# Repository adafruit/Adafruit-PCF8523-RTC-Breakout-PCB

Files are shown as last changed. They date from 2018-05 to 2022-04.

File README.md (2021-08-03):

## Adafruit PCF8523 RTC Breakout PCB

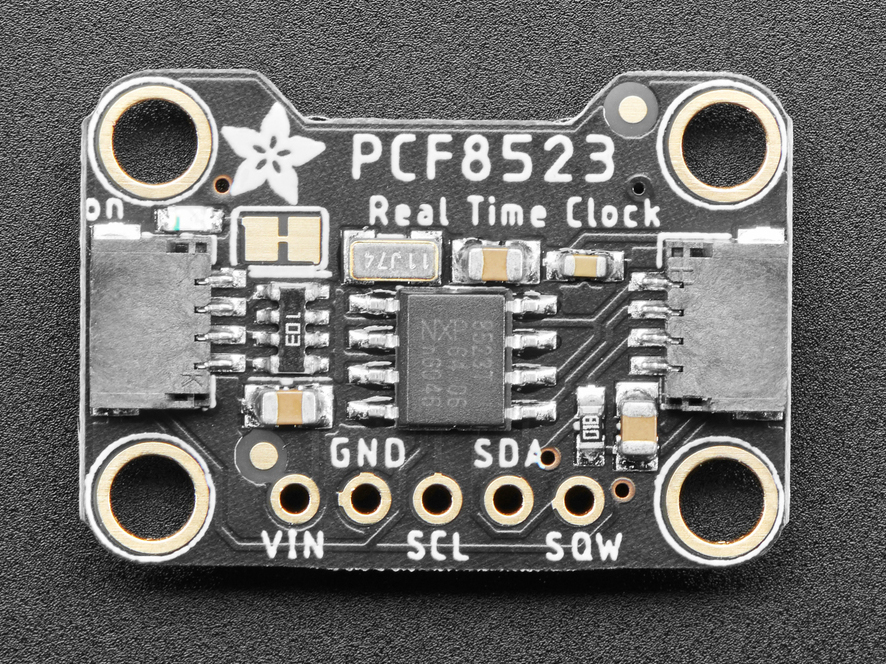
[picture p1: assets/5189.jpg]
<a href="http://www.adafruit.com/products/5189"><br/>
Click here to purchase one from the Adafruit shop</a>

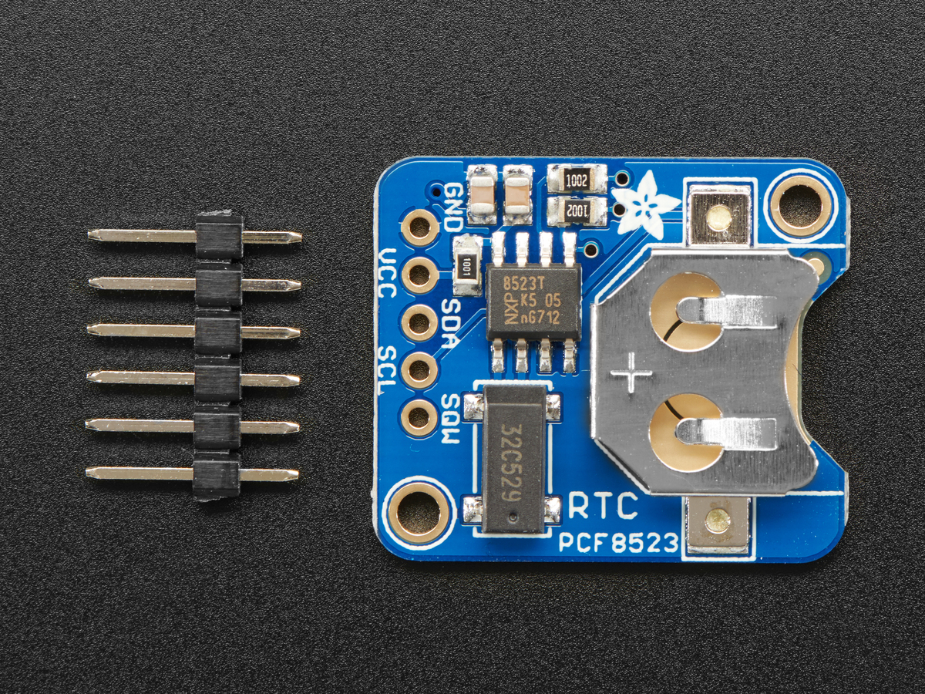
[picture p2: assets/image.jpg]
<a href="http://www.adafruit.com/products/3295"><br/>
Click here to purchase one from the Adafruit shop</a>

PCB files for the Adafruit PCF8523 RTC Breakout. Format is EagleCAD schematic and board layout

For more details, check out the product pages at
* https://www.adafruit.com/products/3295

### Description

This is a great battery-backed real time clock (RTC) that allows your microcontroller project to keep track of time even if it is reprogrammed, or if the power is lost. Perfect for datalogging, clock-building, time stamping, timers and alarms, etc. Equipped with PCF8523 RTC - it can run from 3.3V or 5V power & logic!

Works great with an Arduino using our RTC library, with CircuitPython or with a Raspberry Pi (or similar single board linux computer)

* PCB & header are included
* Plugs into any breadboard, or you can use wires
* Two mounting holes
* Will keep time for 5 years or more

**Note: This product does not come with a CR1220 coin cell battery. We recommend you purchase a coin cell battery to use with this product.**

The PCF8523 is simple and inexpensive but not a high precision device. It may lose or gain up to 2 seconds a day. For a high-precision, temperature compensated alternative, please check out the DS3231 precision RTC. If you need a DS1307 for compatibility reasons, check out our DS1307 RTC breakout

### License

Adafruit invests time and resources providing this open source design, please support Adafruit and open-source hardware by purchasing products from [Adafruit](https://www.adafruit.com)!

Designed by Limor Fried/Ladyada for Adafruit Industries.

Creative Commons Attribution/Share-Alike, all text above must be included in any redistribution. See license.txt for additional details.

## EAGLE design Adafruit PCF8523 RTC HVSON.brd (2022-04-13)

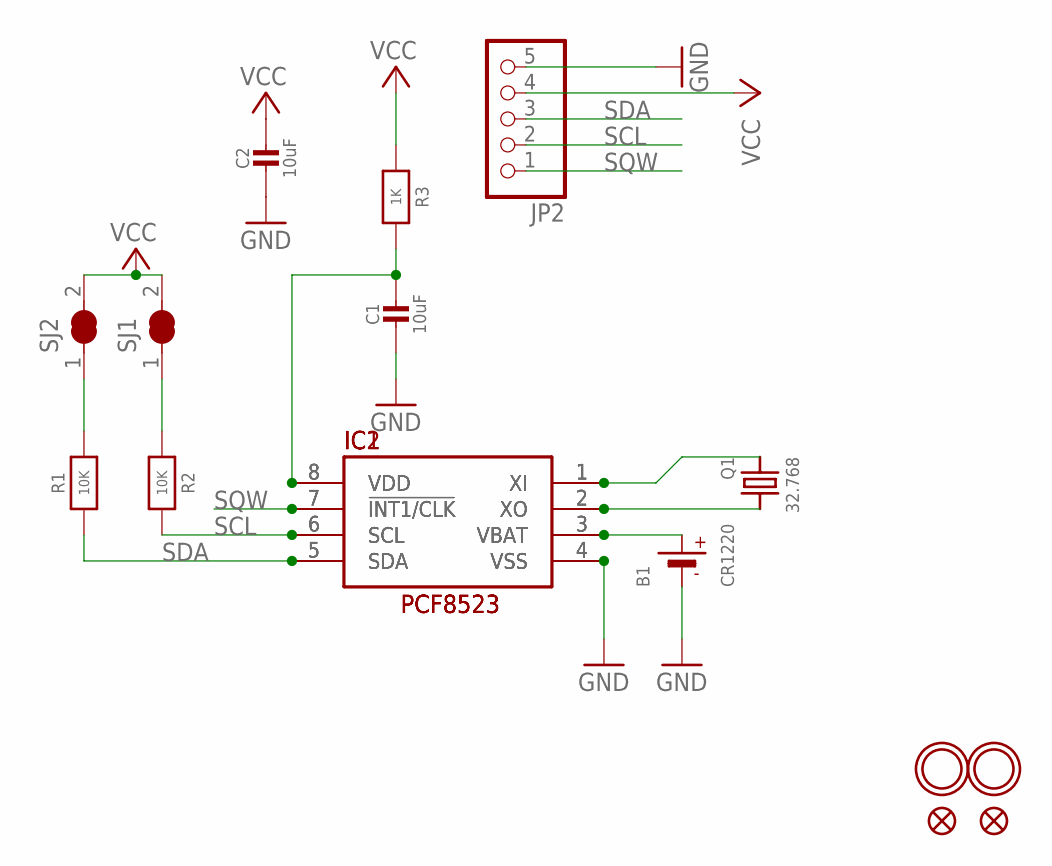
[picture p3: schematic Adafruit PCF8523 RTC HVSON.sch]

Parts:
B1: CR1220
C1, C2: 10uF; 0805-NO
FID1, FID2: FIDUCIAL_1MM
IC1: RTC_PCF8523/T; SOIC8_150MIL
IC2: RTC_PCF8523/TK; HVSON8_4X4
JP2: HEADER-1X576MIL; 1X05_ROUND_76
Q1: 32.768; XTAL3215
R1, R2: 10K; 0805-NO
R3: 1K; 0805-NO
SJ1, SJ2: SOLDERJUMPER_CLOSED; SOLDERJUMPER_CLOSEDWIRE
U$1, U$4: MOUNTINGHOLE2.0; MOUNTINGHOLE_2.0_PLATED

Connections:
GND: B1.-, C1.2, C2.2, IC1.4 (VSS), IC2.4 (VSS), JP2.5
unnamed: R2.1, SJ1.1
unnamed: R1.2, SJ2.1
unnamed: C1.1, IC1.8 (VDD), IC2.8 (VDD), R3.2
unnamed: IC1.1 (XI), IC2.1 (XI), Q1.P$1 (1)
unnamed: IC1.2 (XO), IC2.2 (XO), Q1.P$2 (2)
SCL: IC1.6 (SCL), IC2.6 (SCL), JP2.2, R2.2
SDA: IC1.5 (SDA), IC2.5 (SDA), JP2.3, R1.1
SQW: IC1.7 (!INT1/CLK), IC2.7 (!INT1/CLK), JP2.1
VBAT: B1.+$1 (+), B1.+$2 (+), IC1.3 (VBAT), IC2.3 (VBAT)
VCC: C2.1, JP2.4, R3.1, SJ1.2, SJ2.2

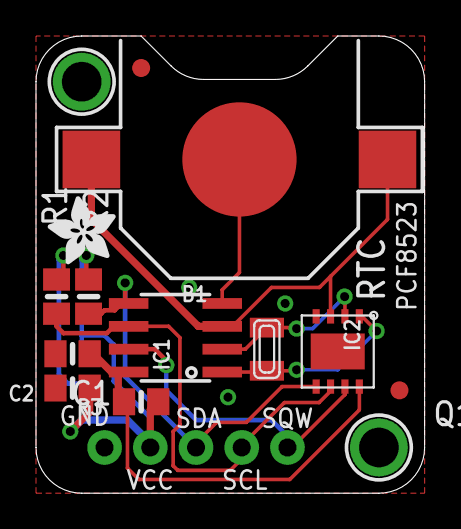
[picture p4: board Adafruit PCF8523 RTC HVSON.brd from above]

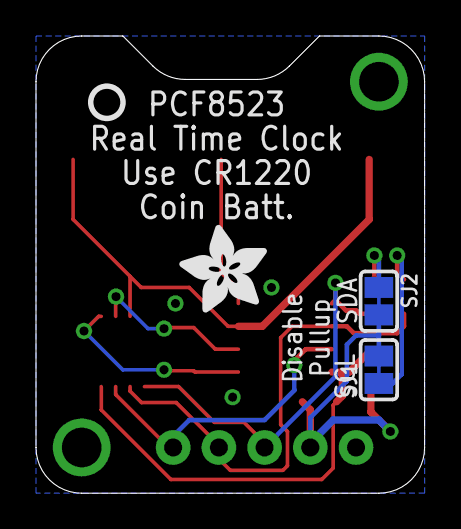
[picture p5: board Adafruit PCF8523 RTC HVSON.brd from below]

Board: 2 copper layers, 21.6 x 25.4 mm, 19 parts (4 on the bottom side), 11 nets.

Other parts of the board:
U$2: ADAFRUIT_3.5MM
U$3: PCBFEAT-REV-040
U$5: ADAFRUIT_5MM

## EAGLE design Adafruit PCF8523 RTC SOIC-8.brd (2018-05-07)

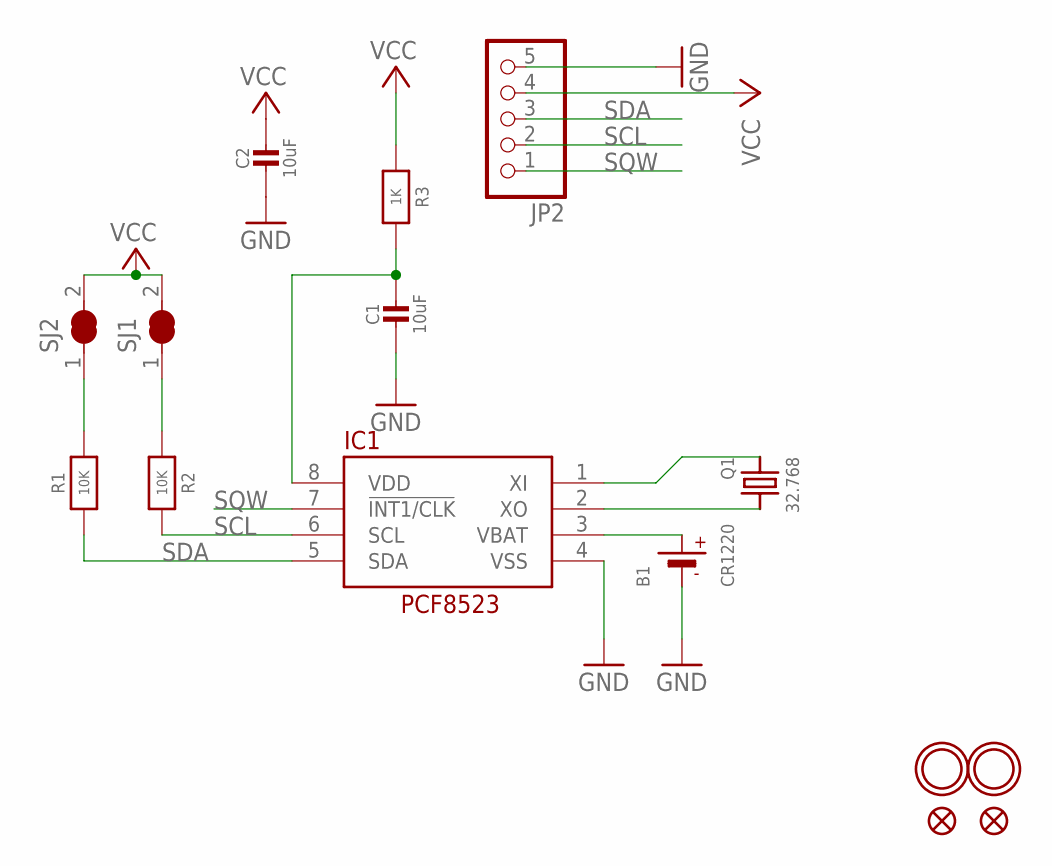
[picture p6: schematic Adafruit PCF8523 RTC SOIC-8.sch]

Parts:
B1: CR1220
C1, C2: 10uF; 0805-NO
FID1, FID2: FIDUCIAL""; FIDUCIAL_1MM
IC1: RTC_PCF8523T; SOIC8_150MIL
JP2: HEADER-1X576MIL; 1X05_ROUND_76
Q1: 32.768; CRYSTAL_8X3.8
R1, R2: 10K; 0805-NO
R3: 1K; 0805-NO
SJ1, SJ2: SOLDERJUMPER_CLOSED; SOLDERJUMPER_CLOSEDWIRE
U$1, U$4: MOUNTINGHOLE2.0; MOUNTINGHOLE_2.0_PLATED

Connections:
GND: B1.-, C1.2, C2.2, IC1.4 (VSS), JP2.5
unnamed: R2.1, SJ1.1
unnamed: R1.2, SJ2.1
unnamed: C1.1, IC1.8 (VDD), R3.2
unnamed: IC1.1 (XI), Q1.P$1 (1)
unnamed: IC1.2 (XO), Q1.P$4 (2)
SCL: IC1.6 (SCL), JP2.2, R2.2
SDA: IC1.5 (SDA), JP2.3, R1.1
SQW: IC1.7 (!INT1/CLK), JP2.1
VBAT: B1.+$1 (+), IC1.3 (VBAT)
VCC: C2.1, JP2.4, R3.1, SJ1.2, SJ2.2

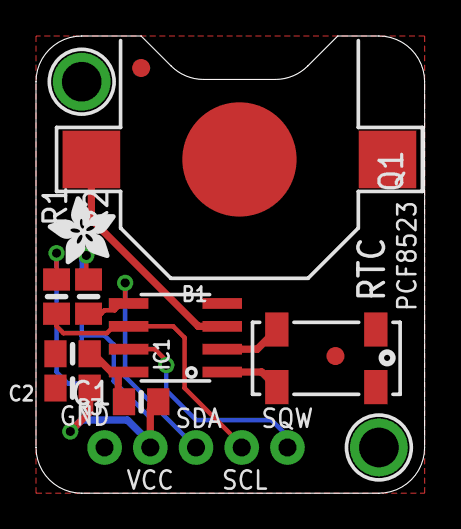
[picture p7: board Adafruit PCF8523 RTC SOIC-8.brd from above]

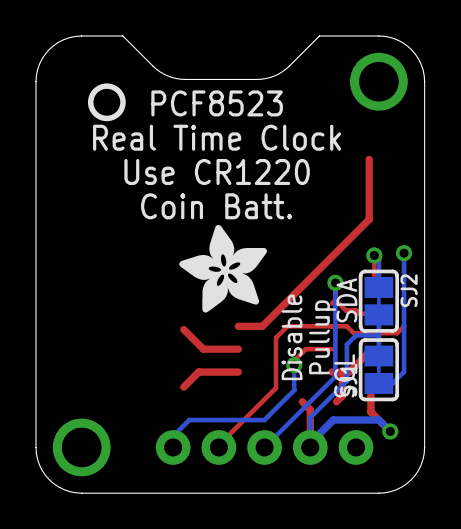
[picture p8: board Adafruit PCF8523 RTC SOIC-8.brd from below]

Board: 2 copper layers, 21.6 x 25.4 mm, 18 parts (4 on the bottom side), 11 nets.

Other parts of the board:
U$2: ADAFRUIT_3.5MM
U$3: PCBFEAT-REV-040
U$5: ADAFRUIT_5MM

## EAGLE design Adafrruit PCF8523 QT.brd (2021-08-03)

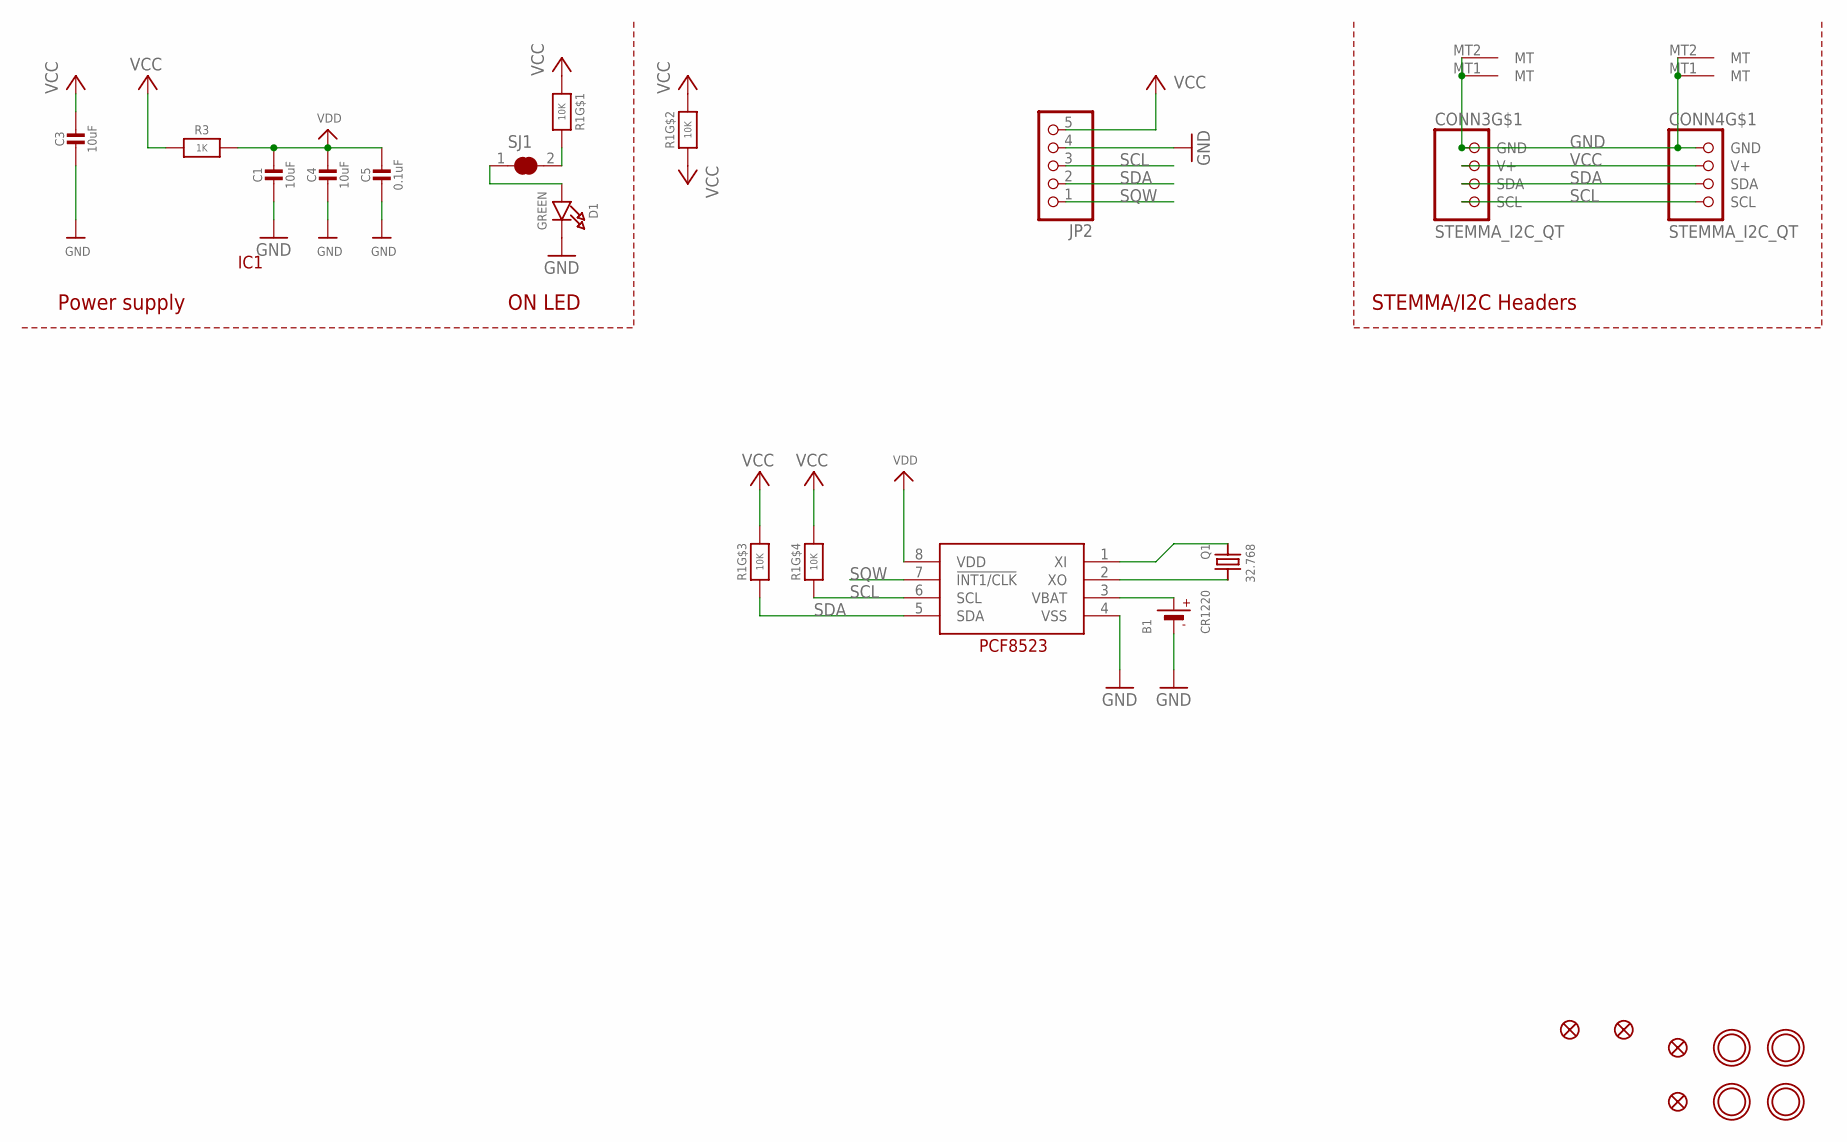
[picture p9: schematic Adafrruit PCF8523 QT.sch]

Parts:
B1: CR1220
C1, C3, C4: 10uF; 0805-NO
C5: 0.1uF; 0603-NO
CONN3, CONN4: STEMMA_I2C_QT; JST_SH4
D1: GREEN; CHIPLED_0603_NOOUTLINE
FID1, FID2, FID3, FID4: FIDUCIAL_1MM
IC1: RTC_PCF8523T; SOIC8_150MIL
JP2: HEADER-1X570MIL; 1X05_ROUND_70
Q1: 32.768; XTAL3215
R1: 10K; RESPACK_4X0603
R3: 1K; 0603-NO
SJ1: SOLDERJUMPER_CLOSED; SOLDERJUMPER_CLOSEDWIRE
U$9, U$17, U$19, U$21: MOUNTINGHOLE3.0THIN; MOUNTINGHOLE_3.0_PLATEDTHIN

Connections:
GND: B1.-, C1.2, C3.2, C4.2, C5.2, CONN3.1 (GND), CONN3.MT1 (MT), CONN3.MT2 (MT), CONN4.1 (GND), CONN4.MT1 (MT), CONN4.MT2 (MT), D1.C, IC1.4 (VSS), JP2.4
unnamed: R1.8 (2), SJ1.2
unnamed: D1.A, SJ1.1
unnamed: IC1.1 (XI), Q1.P$1 (1)
unnamed: IC1.2 (XO), Q1.P$2 (2)
SCL: CONN3.4 (SCL), CONN4.4 (SCL), IC1.6 (SCL), JP2.3, R1.4 (1)
SDA: CONN3.3 (SDA), CONN4.3 (SDA), IC1.5 (SDA), JP2.2, R1.3 (1)
SQW: IC1.7 (!INT1/CLK), JP2.1
VBAT: B1.+$1 (+), B1.+$2 (+), IC1.3 (VBAT)
VCC: C3.1, CONN3.2 (V+), CONN4.2 (V+), JP2.5, R1.1, R1.2 (1), R1.5 (2), R1.6 (2), R1.7 (2), R3.1
VDD: C1.1, C4.1, C5.1, IC1.8 (VDD), R3.2

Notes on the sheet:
STEMMA/I2C Headers
ON LED
Power supply

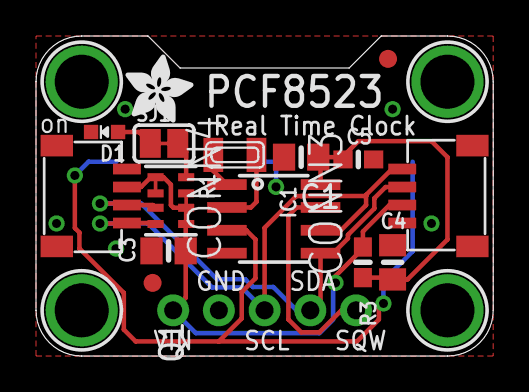
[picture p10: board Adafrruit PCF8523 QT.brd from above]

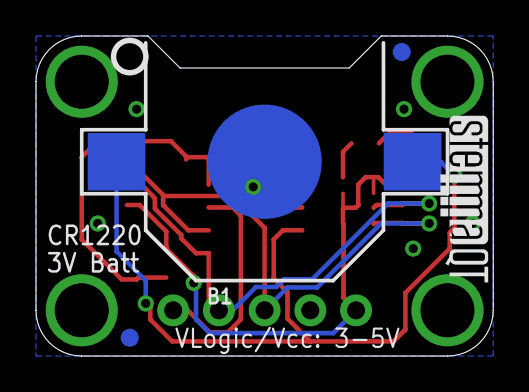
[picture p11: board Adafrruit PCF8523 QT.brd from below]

Board: 2 copper layers, 25.4 x 17.8 mm, 25 parts (5 on the bottom side), 11 nets.

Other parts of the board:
U$22: ADAFRUIT_3.5MM
U$25: PCBFEAT-REV-040
U$31: STEMMAQT

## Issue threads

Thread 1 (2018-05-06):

Eagle files out of date with current design

jeraymond, 2018-05-06:
Hello,

From the [image of the schematic on the Adafruit PCF8523 Real Time Clock page](https://learn.adafruit.com/adafruit-pcf8523-real-time-clock?view=all#schematic) it looks like this board has undergone a revision. There is the addition of a 10uF capacitor and 1k resistor on the VDD pin of the PCF8523 and the VCC bypass capacitor changed from 0.1 uF to 10uF. It'd be great to have the updated Eagle files pushed to Github.

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

The published schematics are such a great learning tool. Thanks a lot for providing them.

ladyada, 2018-05-07:
k!

jeraymond, 2018-05-07:
Thanks! Out of curiosity, what problem did adding the 1k resistor and capacitor to the VDD pin solve?

ladyada, 2018-05-07:
unexpected power droops causing time loss

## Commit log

2021-08-03 Add QT board files.
    [Adafrruit PCF8523 QT.brd, Adafrruit PCF8523 QT.sch]
2022-04-13 Update board files.
    [Adafruit PCF8523 RTC HVSON.brd, Adafruit PCF8523 RTC HVSON.sch, Adafruit PCF8523 RTC SOIC-8.brd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]

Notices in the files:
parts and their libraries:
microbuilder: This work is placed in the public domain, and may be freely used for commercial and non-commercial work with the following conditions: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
